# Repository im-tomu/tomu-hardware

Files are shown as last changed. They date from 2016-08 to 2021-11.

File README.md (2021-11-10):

# Tomu Hardware

[I'm Tomu](tomu.im) a tiny ARM microprocessor which fits in your USB port.
I have two buttons and two LEDs.

Tomu Front Render
Tomu Back Render

## Contact

We're available on mailing lists and IRC:

* [IRC Channel - irc://irc.freenode.net/#tomu](https://webchat.freenode.net/?channels=#tomu) - IRC channel for discussing anything related to the project.
* [Announcement mailing list](https://groups.google.com/forum/#!forum/tomu-announce/join) - Low traffic list for announcements.
* [Discussion mailing list](https://groups.google.com/forum/#!forum/tomu-discuss/join) - List for discussing development / new features / etc.

## About the PCB

Built out of a 3D printed part + 2 layer "thin" PCB.  LCA2018 and Crowd Supply
boards are 0.6mm.

Designs and documentation are available in:

* [`pcb/`](./pcb): [KiCad](http://kicad.org/) design files
* [`docs/`](./docs): PDF schematics, pin-out diagrams, and 3D renders

The board requirements are very lo-fi:

* 6mil traces
* 6mil clearance
* 0.3mm drill / 0.6mm vias

The primary MCU is a Silicon Labs EFM32HG309 ([datasheet](https://www.silabs.com/Support%20Documents/TechnicalDocs/EFM32HG309.pdf), [reference manual](https://www.silabs.com/Support%20Documents/TechnicalDocs/EFM32HG-RM.pdf)).

The important features are:

* [Available on Digikey](http://www.digikey.com/product-detail/en/silicon-labs/EFM32HG309F64G-A-QFN24/336-3207-ND/5142721)
* QFN24 - 5mm x 5mm package
* Inbuilt 5V to 3V3 regulator.
* Crystal-less USB

These make something which is almost hand solder-able fit into the tiny size.

## BOM

All parts are available from Digikey, and are readily available from other suppliers.

* [Kitspace Page](https://kitspace.org/boards/github.com/im-tomu/tomu-hardware/) has links to buy from multiple retailers and download the Gerbers
* [Digikey BOM in CSV format](bom-digikey.csv)
* [Digikey Shared Cart](http://www.digikey.com.au/short/39z1zv)

### Individual Parts

* Resistors
  * 2 x 0402 - 15 Ohm - [Digikey](https://www.digikey.com.au/short/3m8rz5)
  * 2 x 0402 - ~50 Ohm (Depends on LED choice)
* Capacitors - [Digikey Capacitors 0402, >1uF](https://www.digikey.com.au/short/3m8r4z)
  * 2 x Capacitor 1uF 0402
  * 1 x Capacitor 4.7uF 0402
* 2 x LED 0402
  * You choice of two different colors (might require adjustment of R1/R2).
  * 5mA LEDs are better choice.
  * Get highest millicandela rating you can.
  * [Digikey Search of LEDs in 0402 package](https://www.digikey.com.au/short/3m8rz0)
* 1 x EFM32HG309 or EMF32HG308

## Case

The PCB is thinner than a USB socket, and has exposed contacts on the reverse side, so it _needs a case_ in order to make proper contact with the USB pins, and to not short on the shield of the USB port.

Early prototypes used a business card that had been folded over, however the crowd funding campaign made enough to cut steel and make a case.

Designs are available in the [`case/`](./case) directory.  Cases for earlier board versions tend to require higher tolerance on 3D printers.

## FAQ

### Why did you create this?

The aim was to prove that a device which fits in your USB port could be created
**by hobbyists in small quantities** extremely cheaply.

### Where does the name Tomu come from?

TOMU comes from the abbreviation "Tim's Open Micro USB".

### What can I use this for?

What ever you want! If you do create something, please send me the info!

## License

The contents of this repository excluding [`third_party`
directory](./third_party) is released under your choice of the following two
licences:

* the "Creative Commons Attribution-ShareAlike 4.0 International License"
  (CC BY-SA 4.0) full text of this license is included in the
  [LICENSE.CC-BY-SA-4.0](LICENSE.CC-BY-SA-4.0) file and a copy can also be
  found at http://creativecommons.org/licenses/by-sa/4.0/
* the "TAPR Open Hardware License" full text of this license is included
  in the [LICENSE.TAPR](LICENSE.TAPR) file and a copy can also be found at
  http://www.tapr.org/OHL

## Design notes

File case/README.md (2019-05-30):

Tomu Cases
==========

The Tomu PCB has USB contacts on one side, but the other side contains components.  The combined height may not be enough to keep the Tomu PCB inside the USB port.

Early revisions of Tomu used a piece of folded paper to keep the PCB secure.  These cases were designed to alleviate this need.

The cases are designed in FreeCAD, and are distributed both in their source form and their production form.

[tomu\_0.2\_case](tomu_0.2_case.stl)
-------------------------------------

This is the original case.  It is a rectangle, and should work well.

[tomu\_0.2\_case\_fancy](tomu_0.2_case_fancy.stl)
----------------------

This is a fancier case.  It is designed to work with 0.8mm boards, and has a space cut out for the MCU.  It has a lip on the end.

[tomu\_0.3\_case](tomu_0.3_case.stl)
---------------

The Tomu 0.3 revision includes notches on the side for alignment with the PCB.  This case is the same as tomu\_0.2\_case\_fancy, but includes nubs to mate with the notches.

[tomu\_0.4\_case](tomu_0.4_case.stl)
---------------

The Tomu 0.4 revision is 10mm wide, enabling more material on the side for stronger rigidity.  Additionally, an alignment hole was added to the PCB, and this case has a corresponding peg.  Guide rails were added to the sides to make it easier to fit into a USB slot.

[tomu\_0.4\_case\_manufactured](tomu_0.4_case_manufactured.step)
---------------

A .STEP version of the Tomu case that was actually manufactured.  This includes plastic snap tabs to hold the PCB in place, and makes it easier to remove from the slot.

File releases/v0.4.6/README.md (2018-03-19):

# v0.4.6: Crowd Supply Release

This directory contains files for the v0.4.6 production run.

These boards were released as part of the Crowd Supply campaign.

# Files

* [`gerber/`](./gerber): Files output by KiCad
* [`pannelized/`](./pannelized): Pannelization as done by the factory

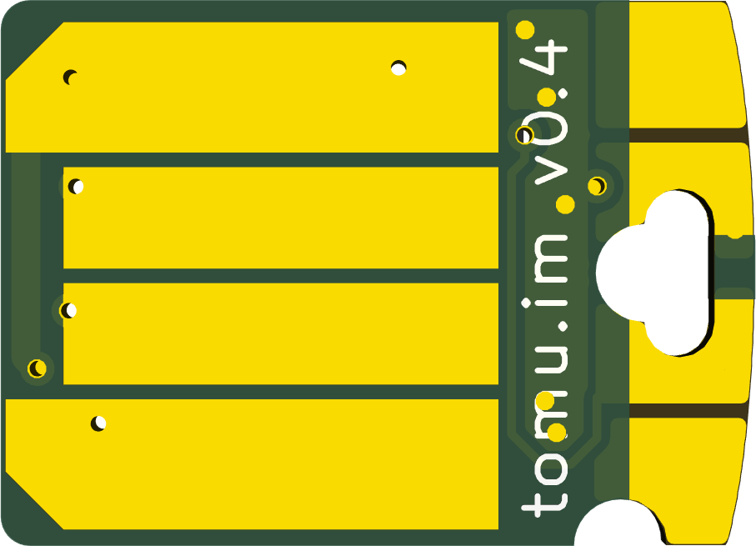
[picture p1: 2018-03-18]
docs/tomu-top-3d.png

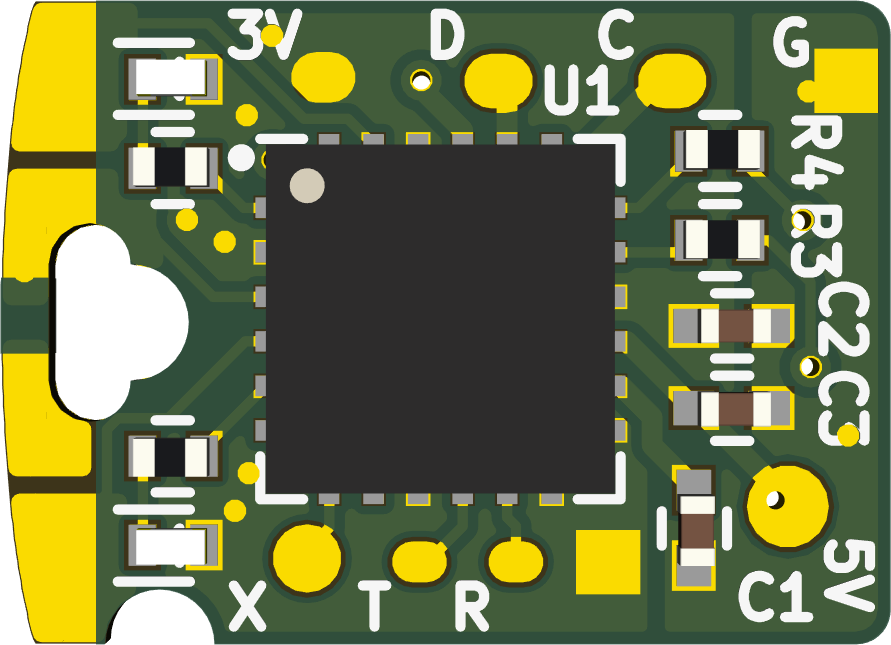
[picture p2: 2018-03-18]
docs/tomu-bottom-3d.png

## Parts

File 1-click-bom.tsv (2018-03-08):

References | Qty | Description | Manufacturer | MPN | Manufacturer | MPN | Manufacturer | MPN | Digikey | Mouser | RS | Newark | Farnell
R3 R4 | 2 | RES SMD 15 OHM 1% 1/16W 0402 | YAGEO (VA) | RC0402FR-0715RL |  |  |  |  | 311-15LRCT-ND | 603RC0402FR0715RL | 6788800 | 26M6782 | 9239014
U1 | 1 | IC MCU 32BIT 64KB FLASH 24QFN | SILICON LABORATORIES INC | EFM32HG309F64G-B-QFN24 | SILICON LABORATORIES INC | EFM32HG309F64G-A-QFN24 |  |  | 336-3896-ND | 634HG309F64GBQFN24 | 8727104 | 47Y0779 | 2475985
C1 C2 | 2 | CAP CER 1uF 10V X5R 0402 | AVX CORPORATION (VA) | 0402ZD105KAT2A | Taiyo Yuden | TMK105BJ105MV-F | Murata | GRM155R61A105ME15D | 587-3245-1-ND | 963TMK105BJ105MVF | 8145237 | 06M4041 | 1740588
C3 | 1 | CAP CER 4.7uF 6.3V X5R 0402 | MURATA ELECTRONICS (VA) | GRM155R60J475ME47D | Taiyo Yuden | JMK105BBJ475MV-F |  |  | 587-2787-6-ND | 963JMK105BBJ475MVF | 8145230 | 68X2780 | 2426952
D1 | 1 | LED GREEN CLEAR 0402 SMD | KINGBRIGHT COMPANY LLC (VA) | APG1005VGC-T-5MAV |  |  |  |  | 754-1815-1-ND | 604APG1005VGCT5MAV | 1246874 | 23X4794 | 2062324
R1 R2 | 2 | RES SMD 52.3 OHM 1% 1/16W 0402 | YAGEO (VA) | RC0402FR-0752R3L |  |  |  |  | YAG3180CT-ND | 603RC0402FR0752R3L | 7014444 | 90W3929 | 2140645
D2 | 1 | LED RED 0402 SMD | PANASONIC ELECTRONIC COMPONENTS (VA) | LNJ247W82RA |  |  |  |  | LNJ247W82RACT-ND | 667LNJ247W82RA | 7870207 | 66W2425 | 2112119

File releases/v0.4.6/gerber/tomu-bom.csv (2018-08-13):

Reference | Value | Footprint | Count | Datasheet | FootprintLib | MPN | Manufacturer | Description | Notes
C2 | 1uF, 10V, X5R, 0402 | C_0402 | 1 |  | Capacitors_SMD | ANY | ANY
C3 | 4.7uF, 6.3V, X5R, 0402 | C_0402 | 1 |  | Capacitors_SMD | ANY | ANY
C1 | 1uF, 10V, X5R, 0402 | C_0402 | 1 |  | Capacitors_SMD | ANY | ANY
P3 | USB-PCB | USB-PCB | 1 |  | usb-pcb |  |  | USB pads on bottom of PCB | DNP
R3 | 15 Ohm, 1%, 1/16W, 0402 | R_0402 | 1 |  | Resistors_SMD | ANY | ANY
R4 | 15 Ohm, 1%, 1/16W, 0402 | R_0402 | 1 |  | Resistors_SMD | ANY | ANY
D1 | LED Green 0402 | LED_0402 | 1 |  | LEDs | ANY | ANY
D2 | LED, Red, 0402 | LED_0402 | 1 |  | LEDs | ANY | ANY
R2 | 100 Ohm, 1%, 1/16W, 0402 | R_0402 | 1 |  | Resistors_SMD | ANY | ANY
R1 | 100 Ohm, 1%, 1/16W, 0402 | R_0402 | 1 |  | Resistors_SMD | ANY | ANY
W1 | CAP0 | Test_Point_2Pads | 1 |  | Measurement_Points |  |  | Capacitive touch pads | DNP
W2 | CAP1 | Test_Point_2Pads | 1 |  | Measurement_Points |  |  | Capacitive touch pads | DNP
U1 | EFM32HG309 | QFN-24-1EP_5x5mm_Pitch0.65mm | 1 | https://www.silabs.com/documents/public/data-sheets/EFM32HG309.pdf | Housings_DFN_QFN | EFM32HG309F64G-B-QFN24 | Silicon Laboratories Inc
P2 | DEBUG | pads-1x3 | 1 |  | usb-pcb |  |  | Test points for SWD | DNP
P4 | RESET_PAD | pads-1x1 | 1 |  | usb-pcb |  |  | Test point for RESET line | DNP
P5 | 5V_PAD | pads-1x1 | 1 |  | usb-pcb |  |  | Test point for supplying 5V power | DNP
XX1 | Button solder mask removal | soldermask-removal | 1 |  | usb-pcb |  |  | Internal component to expose captouch pads | DNP
XX3 | ESD Bag |  | 1 |  |  |  |  | Small bag to contain PCB and plastic case. Approx. 90mm x 90mm. | DNP
XX4 | Plastic Case |  | 1 |  |  |  |  | Case to be consigned from external plastics vendor | DNP
P1 | USART0 | pads-1x3-slim | 1 |  | usb-pcb |  |  | Test points for serial | DNP
P6 | 3V_PAD | pads-1x1 | 1 |  | usb-pcb |  |  | Test point for 3.3V power | DNP
XX2 | ESD Bag Sticker |  | 1 |  |  |  |  | Black-and-white sticker to affix to ESD bag. 30mm x 50mm | DNP

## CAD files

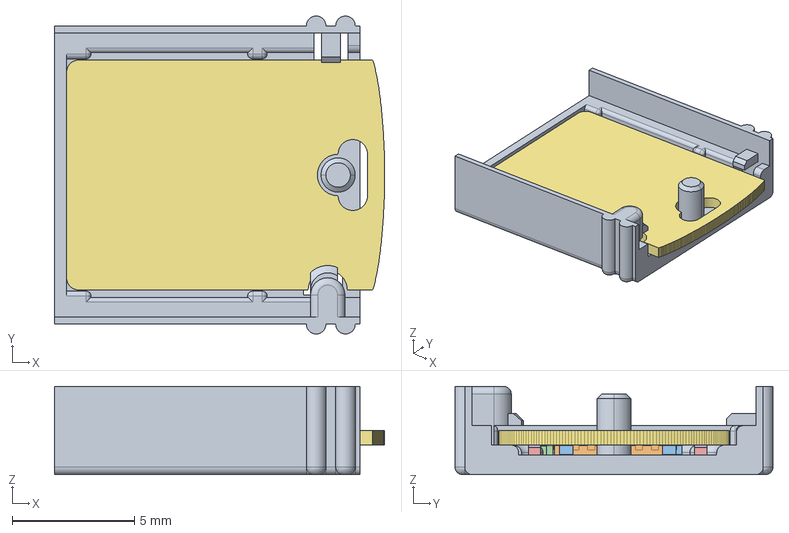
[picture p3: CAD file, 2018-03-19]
case/tomu_0.4_case_manufactured.step
13.5 x 13.0 x 3.60 mm
TOMU_0_4_CASE_SHORT-V01
QFN-24-1EP_5X5MM_PITCH0_65MM_
R_0402_002
R_0402_003
R_0402_001
R_0402_
C_0402_
MANIFOLD_SOLID_BREP_28906
MANIFOLD_SOLID_BREP_29236
C_0402_001
C_0402_002
MANIFOLD_SOLID_BREP_69845
MANIFOLD_SOLID_BREP_70175
PCB

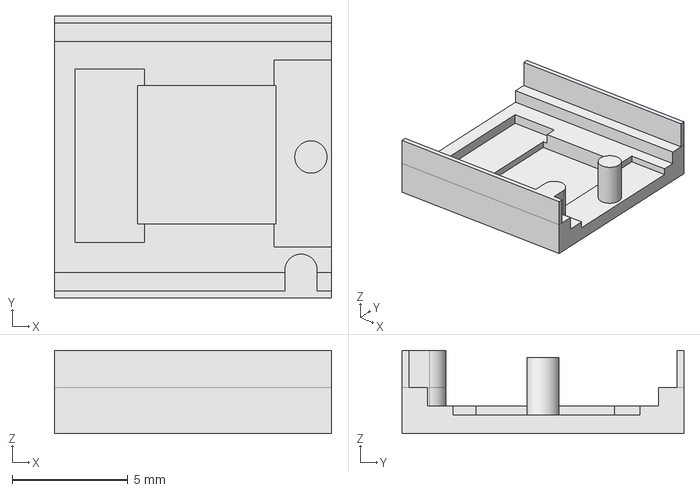
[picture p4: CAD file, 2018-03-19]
case/tomu_0.4_case.step
12.0 x 12.2 x 3.60 mm

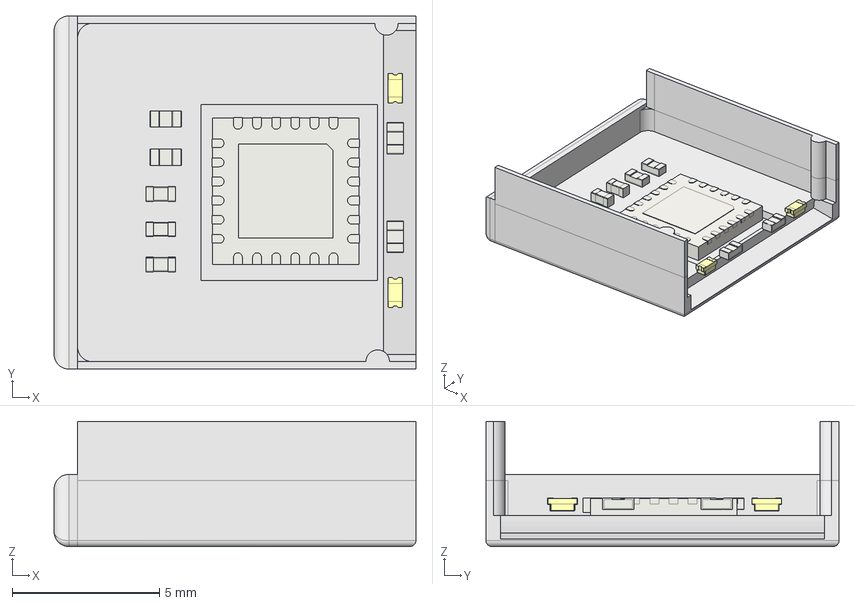
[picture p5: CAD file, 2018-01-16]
case/tomu_0.3_case.FCStd
12.3 x 12.0 x 4.25 mm
R_0402_
User Library-led_0402_
C_0402_
C_0402_001
C_0402_002
User Library-led_0402_001
R_0402_001
R_0402_002
R_0402_003
QFN-24-1EP_5x5mm_Pitch0.65mm_

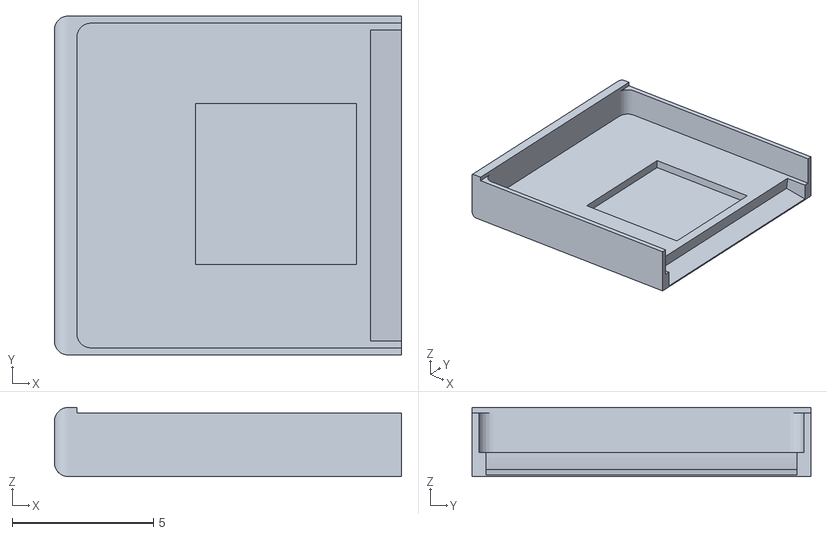
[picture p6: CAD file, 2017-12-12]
case/tomu_0.2_case_fancy.stl
12.3 x 12.0 x 2.45

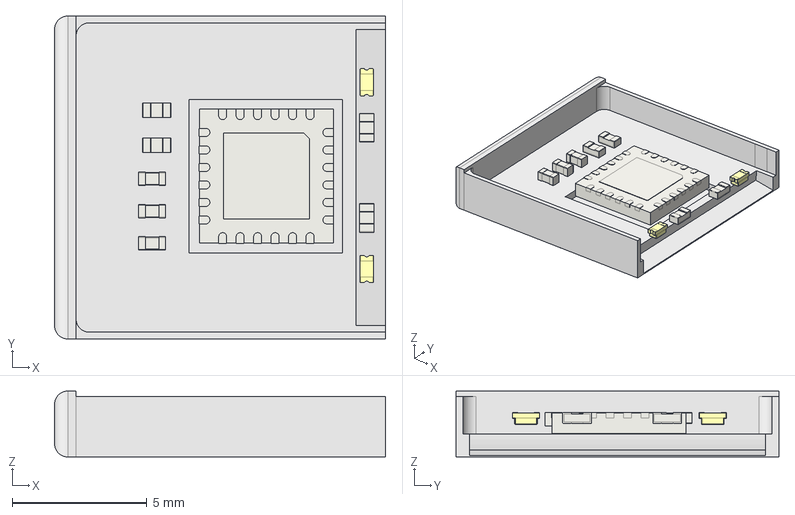
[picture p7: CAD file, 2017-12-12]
case/tomu_0.2_case.FCStd
12.3 x 12.0 x 2.45 mm
R_0402_
User Library-led_0402_
C_0402_
C_0402_001
C_0402_002
User Library-led_0402_001
R_0402_001
R_0402_002
R_0402_003
QFN-24-1EP_5x5mm_Pitch0.65mm_

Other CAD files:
case/tomu_0.4_case_short.step
case/tomu_0.2_case.stl
case/tomu_0.3_case.stl
case/tomu_0.4_case.FCStd
case/tomu_0.4_case.stl

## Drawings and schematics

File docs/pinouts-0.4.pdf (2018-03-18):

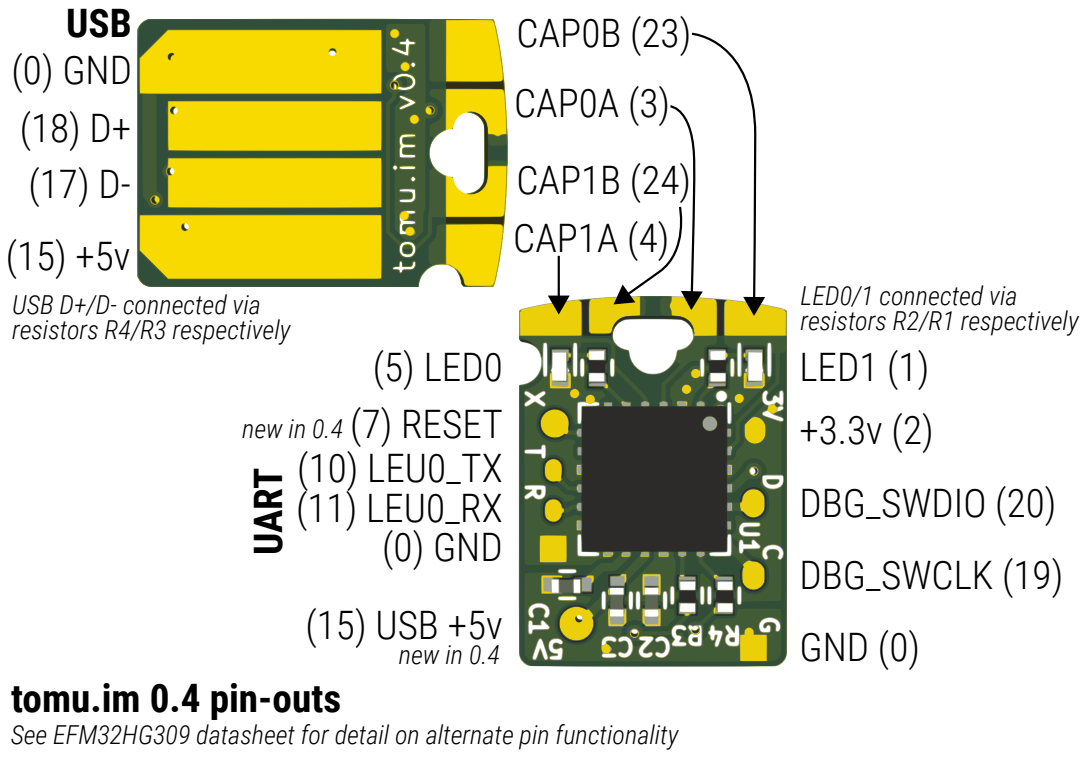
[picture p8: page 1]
DBG_SWDIO (20); DBG_SWCLK (19); GND (0); LED1 (1); CAP1A (4); CAP1B (24); CAP0A (3); CAP0B (23); (0) GND; USB; USB D+/D- connected via resistors R4/R3 respectively; (7) RESET; (5) LED0; (15) USB +5v new in 0.4; new in 0.4 (10) LEU0_TX (11) LEU0_RX; UART; LED0/1 connected via resistors R2/R1 respectively

tomu.im 0.4 pin-outs
See EFM32HG309 datasheet for detail on alternate pin functionality

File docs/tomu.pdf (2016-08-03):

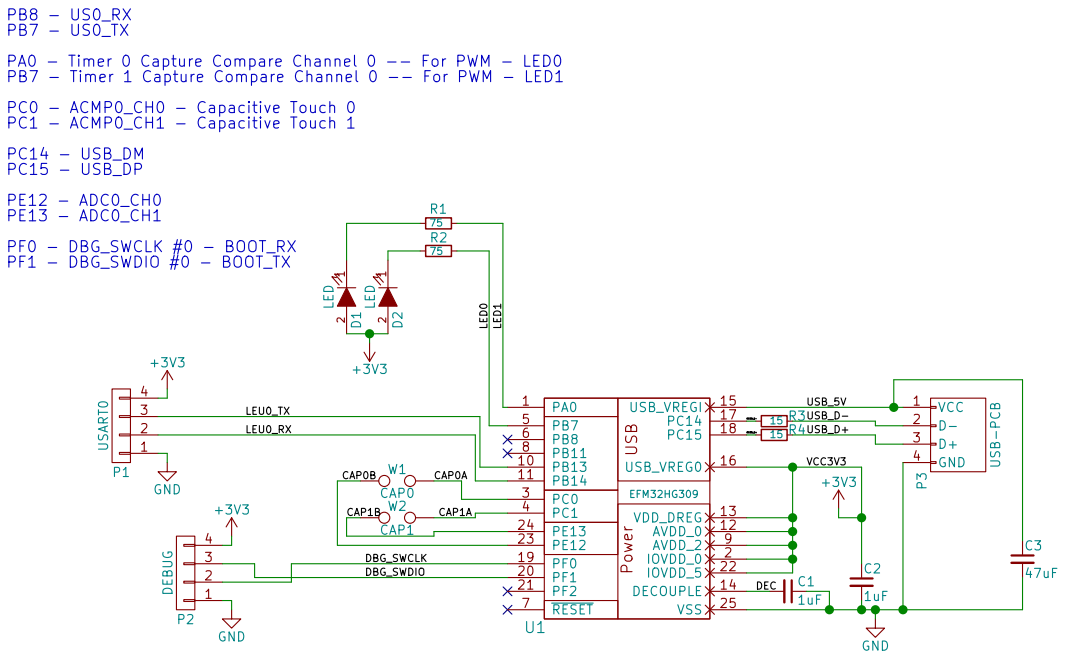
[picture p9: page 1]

https://github.com/mithro/tomu C2
1uF GND

http://tomu.im
License: CC-BY-SA 4.0 or TAPR
File: tomu.sch Sheet: / Tim 'mithro' Ansell <mithro@mithis.com>

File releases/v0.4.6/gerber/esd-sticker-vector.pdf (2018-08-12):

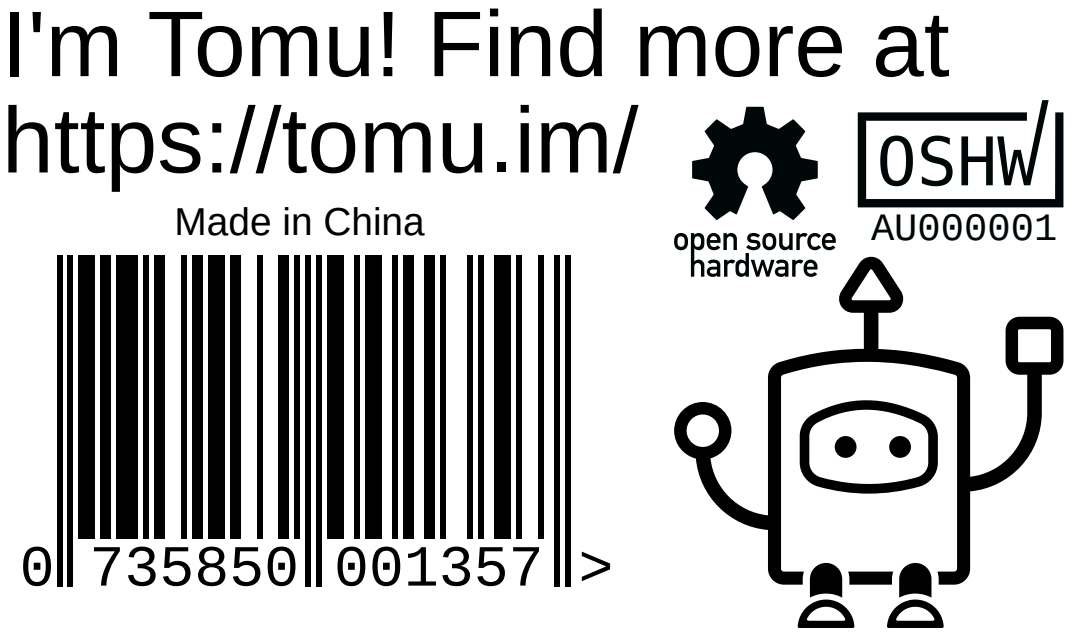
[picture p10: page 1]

I'm Tomu! Find more at
https://tomu.im/

Made in China

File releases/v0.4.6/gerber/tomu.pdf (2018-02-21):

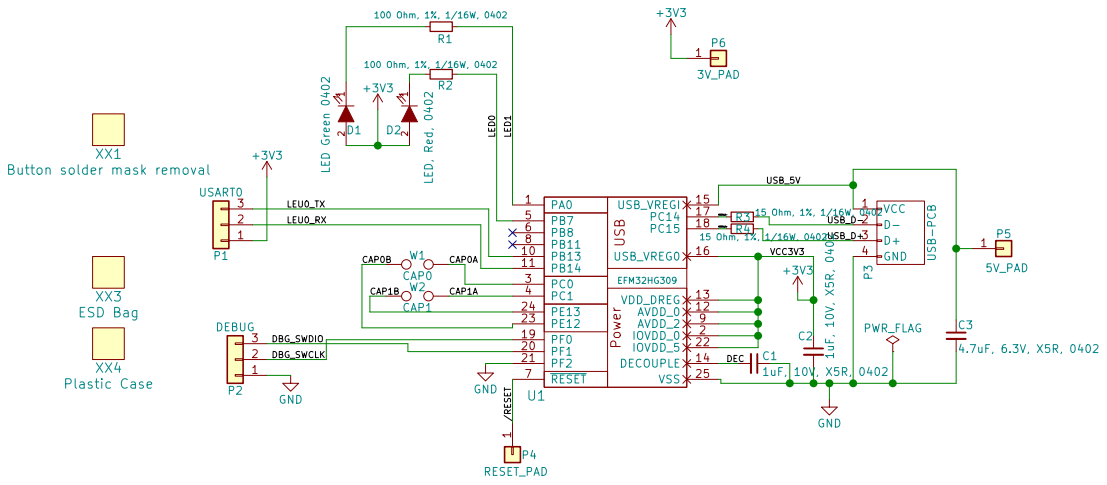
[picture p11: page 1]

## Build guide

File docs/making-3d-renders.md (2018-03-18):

# Making 3D renders

This walks through the steps involved in making a 3D render, and annotating it in an SVG file.

You'll need both KiCad and Inkscape installed. This document assumes some level of familiarity with Inkscape.

## Render the PCB

1. Load `./pcb/tomu.pro` in KiCad.

2. Open `tomu.sch` from within the project.

3. `View` > `3D Viewer`.

Viewport parameters used for export:

- `dx` = 0
- `dy` = 0
- `zoom` = 16.4
- `background colour`: white (#FFFFFF)

Use the fixed top view and bottom view.  Bottom view also requires rotation on the Y axis by 180 degrees.

Export as PNG.  Flatten the image and autocrop.

These should come out as:

- Top: 907x655 px
- Bottom: 891x645 px

Don't worry about resizing them or if they don't match exactly. You just need to get "enough" resolution that it looks nice in Inkscape.

## Import into Inkscape

Parameters used for Inkscape:

- Page size: A4 (landscape) / 297 x 210 mm
- Object size: 100mm wide (fixed aspect ratio)

Import the two images (the top and bottom) into Inkscape, into the same document.

For each image:

1. `Path` > `Trace Bitmap`

2. Select `Multiple Scans` > `Colors`, and tick `Remove background`.  Other options should be left as defaults.

3. Click `OK`.  This will take a couple of seconds to scan the image (the OK button will be disabled while processing), and then you can close the Trace window.

4. The Trace (group) will be placed on top of the Image.  Move them apart, and delete the Image, so you have only the trace.

5. Adjust the size of the trace to be 100mm width (fixed aspect ratio).

Save the document as SVG.  You will now have two vectors that you can use to annotate the PCB in Inkscape.

## Style

The main font used is `Roboto Condensed`.

* Headers: Bold font width
* Other text: Light font width

## PDF

Export as PDF using Inkscape. Include embedded fonts.

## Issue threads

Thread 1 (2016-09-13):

Commit design for 3d printable case

mithro, 2016-09-13:

mithro, 2016-09-13:
@phlipped can you send me a pull request with the design in it? Thanks!

mithro, 2017-01-06:
This was done in https://github.com/im-tomu/tomu-hardware/pull/11

Closed 2017-01-06.

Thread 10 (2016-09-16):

Create a QEMU emulation environment

mithro, 2016-09-16:
@shenki was doing something here....

shenki, 2016-09-16:
Follow along at https://github.com/shenki/qemu/tree/efm32hg

Current state builds but does not work. I've got local changes that implement the leuart, will push once they are working.

mithro, 2016-09-16:
How hard / possible is emulating the USB side of things?

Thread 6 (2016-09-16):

Test the LEUART

mithro, 2016-09-16:
Test that the LEUART can be used on the UART pins.

joshgoes, 2016-09-16:
The D and C pins are LEUART0 location 3, and T and R pins are LEUART0 location 1.

Because D and C are also used by ARM SWD (which is enabled by default), it's important to remember to configure the multiplexer to use location 1 when enabling the LEUART.

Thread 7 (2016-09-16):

Test the ARM SWD

mithro, 2016-09-16:
Test that the CPU can be debugged via the ARM SWD pins using OpenOCD and GDB.

maks, 2017-01-20:
@mithro which pads on the board are the SWD pins brought out to?
I want to have a go at using SWD with a buspirate and openocd to do the initial flashing [per this guide](https://www.earth.li/~noodles/blog/2015/08/program-fst01-with-buspirate.html).

sa-wilson, 2017-01-27:
@maks C and D are the SWD pins. CLK and DIO respectively.

I screwed up the UART bootloader upgrade and then had to use OpenOCD and an STLink-v2-1 to flash the bootloader back, so I know that particular combination works. Only OpenOCD 0.10 has Happy Gecko support though. I didn't try any debugging.

mithro, 2017-02-03:
Instructions on using ARM 2-wire with OpenOCD on a RPi are now at
https://github.com/im-tomu/tomu-bootloader/tree/master/openocd

It's definitely working, so closing this issue.

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

Closed 2017-02-03.

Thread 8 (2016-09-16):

Create a easy programmer rig

mithro, 2016-09-16:
Something with spring-loaded contacts / pogo pins....

mithro, 2016-09-16:
Needs a USB->Serial interface to enable loading of the initial firmware.

maks, 2017-01-20:
Only just started reading the [mcu's documentation](https://www.silabs.com/Support%20Documents/TechnicalDocs/EFM32HG309.pdf) and initially spotted:

> 2.1.13 Pre-Programmed USB/UART Bootloader

Is there a reason why this can not be used for easy firmware flashing?

maks, 2017-01-20:
Reading the [app note](https://www.silabs.com/Support%20Documents/TechnicalDocs/AN0042.pdf) you can use either USB or UART, so I guess next question is are the T/R pins USART0 ?

joshgoes, 2017-01-20:
> Is there a reason why this can not be used for easy firmware flashing?

Yes - the pre-programmed USB/UART Bootloader depends on an external high-frequency XTAL for USB functionality, despite there being a perfectly good internal high-frequency XTAL for USB. This is an oversight on Silicon Labs' part. As the Tomu has no external XTAL, the USB functionality is nonexistent. This is why we have to use the (Silicon Labs provided) AN0042 bootloader. It is more-or-less identical to the factory-programmed bootloader but with the XTAL stuff fixed up, and the version string changed slightly.

> Reading the app note you can use either USB or UART, so I guess next question is are the T/R pins USART0 ?

The UART mentioned in the bootloader docs is actually an LEUART, which is wired to the D/C pins. This means that the D/C pins are used by both SWD as well as a low-energy UART.  The T/R pins are wired to a different UART to the D/C pins. This allows people to have SWD and UART (or two UARTs) going at the same time.
I can't remember in which doc (or where in the doc), but there's a table of all the peripherals plus their "locations" -- with pins. Check out the Tomu schematic to find which pins T/R are wired to, and then check the table to see which UART+Location combos are available at those pins.

maks, 2017-01-20:
Now that @mithro emailed out about the project discuss google group, I see the post there from @joshgoes already covers how to use the builtin bootloader to flash via uart.

kevinb456, 2018-11-14:
I've just noticed this on a browse of interesting kitspace.org projects - I have had success in my work capacity in designing simple programming sprung-probe rigs so could share some ideas for this.

I've found that a mechanical base designed in Freecad, and printed on a 3D printer can be quite effective. Probes/sleeves such as Harwin P19-4021 and S19-501 can contact to the SWD pins, and can be inserted straight into the 3D printed base if designed with a tight fit. Also attach a clamp such as Brauer H100/2 to the base which brings a second 3D printed 'press' part down on top of the PCBA. Then combining with a programmer such as an LPC-Link2, and the whole thing bundled up inside a plastic enclosure works well - insert PCBA, close press with handle, program PCBA, open press & remove... rinse&repeat! Depending on volume this could be expanded to do a panel at once with multiple programmers.

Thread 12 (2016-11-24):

Make the tomu PCB work with OSH park

mithro, 2016-11-24:
See http://docs.oshpark.com/submitting-orders/cutouts-and-slots/

Currently the slot doesn't work;

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

flummer, 2016-12-30:
I'll be happy to look into this... Since this slot isn't plated (that would short two of the pads), this can be milled along with the outline, so if the hole is replaced with an additional outline (inside cut-out), the same file should work with OSH park and the other fab houses.

I'll be happy to do that and send a pull request, just need to separate some of the stuff in the current design first.

pdp7, 2017-02-14:
Hi @flummer, thanks for making this change.  I work for OSH Park and have just ordered your modified version: https://oshpark.com/projects/4tCH773A

I used our 0.8mm thickness service.  Our normal 1.6mm thick 2 layer panels go out daily, but this one is less frequent.  The current 0.8mm panel is already at 50%, so it should be going to fab on Friday.  I should have it be the end of February.

I'll order an OSH Stencil and the parts and attempt to assemble.  I've used paste before with SOIC but not a QFN, so it will be an interesting experience.

bokowski, 2018-02-26:
One year later... I thought I'd update this issue saying that the board (OSH Park link above) works.

vincenttl, 2018-03-27:
Hi, I build a Tomu from oshpark: https://oshpark.com/shared_projects/ZAMlmpMB
It seems to be working.
Got the bootloader running and this too https://github.com/im-tomu/chopstx/tree/efm32/example-tomu

The touch seems to work fine. Anything else I should try?

mithro, 2018-04-02:
Got some pictures? Did the hole/slot work?

vincenttl, 2018-04-02:
Here is one of the 3. It would need to be cleaned up a little bit.
I also left it a bit too long on the hot plate for soldering.

I continued playing with it and there might be an issue.
I flashed the dfu bootloader without issue but it comes back to the
bootloader every power cycle even if I used dfu-utils to program the u2f
firmware. I checked for a short between the outer pads and they are not
shorted.

I'll investigate soon.

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

todbot, 2018-04-02:
The bootloader always running is not a short in your circuit.  It's apparently by design: https://github.com/im-tomu/tomu-bootloader/issues/31

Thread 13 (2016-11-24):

Order and test tomu boards from Dirty PCBs

mithro, 2016-11-24:
http://dirtypcbs.com/

mithro, 2016-11-24:
Your order number:2027981
```
PCBs	File	Layers	Size (actual)		Color	Thickness	Coating	Stencil	Processing	Quantity	Charge	Status
28514	xx	2	5x5cm(1.1x1.3cm)	Yellow	1.0mm		HASL	None	Normal		Protopack ±10	$14	Order received

Shipping	Hongkong Airmail (1-8+ weeks)	$0	0.1kg
Total	 	$14
xxx - tomu-v0.2-11-g07748ae.zip
```

mithro, 2016-11-24:
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

luftek, 2017-01-28:
DirtyPCB do panelized 2 layer boards. Like:
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

I use https://github.com/ThisIsNotRocketScience/GerberTools , works great. Their tools are also used for rendering the DirtyPCBs

A append an example of your v0.2 board but multiplied on a 10x10cm prototype panel. Roughly 36 times 10-12 panels which is around **400pcs for 25$ (panel + shipping)**
Your panelized board would look like that:
- choose red color :)
- breaktabs can be made smaller, for easier depanelization
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

I make a pull request?

mithro, 2017-01-30:
Make sure you order the thinner PCB - please do send a pull request.

luftek, 2017-01-30:
I don't have a use for im-tomu right now -> won't order samples.
Just wanted to let you know. Tell which size you choose for panelizing (5x5 OR 10x10 cm) and I will do it (pull request).

mithro, 2017-01-30:
Lets do both?

luftek, 2017-01-30:
Sure

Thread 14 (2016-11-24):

Order and test tomu boards from Seeed Studio

mithro, 2016-11-24:
https://www.seeedstudio.com/fusion.html

mithro, 2016-11-24:
```
Fusion PCB
SKU: 501010001
$9.90 × 1
PCB Dimension - 11mm*13mm
Impedance Control - No
Surface Finish - Hasl
Copper Weight - 1oz.
Half-cut / Castellated Holes - No
Min Hole Size - 0.3mm
PCB Color - Blue
Material - FR4
Layer - 2
PCB Qty. - 10
Blind Vias - No
PCB Thickness - 1.0mm
Min Tracking / Spacing - 6/6mil
Panelized PCBs - 1
File - D_358425_tomu_v0_2_11_g07748ae.zip
```

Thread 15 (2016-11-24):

Panelize the tomu board -- for cheaper production

mithro, 2016-11-24:

luftek, 2017-01-28:
Check #13

xobs, 2018-09-11:
There are pannelized gerbers in https://github.com/im-tomu/tomu-hardware/tree/master/releases/v0.4.6/pannelized, which are the actual files used during production.

Closed 2018-09-11.

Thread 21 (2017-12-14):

U1 pin 1 marker is confusing

xobs, 2017-12-14:
The "pin 1" marker for U1 is very subtle, and multiple assembly shops have had trouble identifying it.

"pin 1" should be changed to use the more traditional "pin 1 dot", rather than the current arrangement of a broken box.

xobs, 2018-03-09:
This was fixed in v0.4

Closed 2018-03-09.

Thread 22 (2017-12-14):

Reset pin not connected

xobs, 2017-12-14:
The /RESET pin (pin 7 of the MCU) is not made available. This is an issue when working on the bootloader.

Ordinarily, the system relies on being able to send a JTAG reset. This is fine if the MCU isn't locked up. However, if the MCU crashes then it is impossible to reattach gdb without a reset.

In order to develop on the bootloader itself, /RESET should be brought out to a pad.

xobs, 2018-03-09:
This pin is brought out in v0.4

Closed 2018-03-09.

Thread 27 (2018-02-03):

Flashprint complains the 0.4 short case has errors

deece, 2018-02-03:
No details provided, my guess is the STL fails the manifold check.

xobs, 2018-02-03:
I don't have Flashprint, so I can't reproduce.  However, I've run that STL file through MeshFix.  Does 39df12e0c3616080f021085e6e30da3359f7ce82 solve the issue?

deece, 2018-02-08:
Yup, that fixed it, thanks

Closed 2018-02-08.

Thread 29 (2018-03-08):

Schematics image, but with a photo/diagram of the physical layout

micolous, 2018-03-08:
I was having a look to see what is brought out from the EFM32HG309 on the back of the board, and so my first port of call was `/docs/tomu.pdf`.  But this shows the logical layout.  There's also no indication about which version of the board it applies to.

What would help is if there were pictures/diagrams of the actual, physical layout of the board, pointing to what each pad corresponds to on the EFM32HG309.

This would help people who are less skilled with electronics to know what they're wiring on to.

I _think_ what it is:

- The 4 pads on the top labelled with "D" and "C" are the debug interface, and, from left to right:
  1. 3.3v
  2. SWDIO
  3. SWDCLK
  4. Ground (square)
- The 4 pads on the bottom, labelled with "T" and "R" are the (Low Energy) UART interface, and, from left to right:
  1. 3.3v
  2. PB13 / LEU0_TX
  3. PB14 / LEU0_RX
  4. Ground (square)
- The four contacts on the left edge are the touch-sensitive pins, not sure what is connected to what there, but could also be repurposed for analogue or digital I/O.

mithro, 2018-03-08:
There is some info here -> https://github.com/im-tomu/tomu-bootloader/tree/master/openocd#wiring

mithro, 2018-03-08:
We would love for someone to create pin diagrams like those found on http://fritzing.org/parts/ or http://diwo.bq.com/pinout-uno/

Closed 2018-03-18.

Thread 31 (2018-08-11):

ROHS compliance

InnovativeInventor, 2018-08-11:
I see that all of the components listed [here](https://github.com/im-tomu/tomu-hardware/blob/master/bom-digikey.csv) are ROHS compliant (awesome!), but is the solder you use ROHS compliant as well? Also, are there plans to get tomu ROHS-certified? Keep up the good work!

InnovativeInventor, 2020-07-31:
Update: https://groups.google.com/forum/#!topic/tomu-discuss/4NW_Z1UTspo

Closing the issue for now.

Closed 2020-07-31.

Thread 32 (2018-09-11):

Minor inconsistency in BOM documentation.

hackup, 2018-09-11:
The README lists "1 x Capacitor >10uF 0402" under "individual parts". In the other BOM documents and links presumably the same part is listed as 4.7uF.

xobs, 2018-09-11:
Thanks, fixed!

hackup, 2018-09-11:
I think this is still not quite right. According to the schematics, both C1 and C2 are 1uF and C3 is 4.7uF. There doesn't seem to be a cap >10uF.

hackup, 2018-09-11:
Glad to hear that because those are the components I ordered. :-) Thanks!

Closed 2018-09-11.

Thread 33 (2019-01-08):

Store data inside flash

dzonerzy, 2019-01-08:
As it states there's a way to store data inside tomu?

xobs, 2019-01-09:
To the best of my knowledge, there aren't any examples of this yet.  You need to be very, very careful, because you can very easily erase Toboot, meaning your board won't boot anymore.

An example of something that stores data on the flash is Booster (https://github.com/im-tomu/tomu-bootloader/blob/master/booster/main.c#L127), which is used to update Toboot.

Tomu has 1024-byte pages.  Since there are 64 kB on the device, that means there are 64 pages in total.  Toboot takes up the first 8 pages.

To program data, you must:

1. Erase a 1024-byte block
2. Program your data in 4-byte words.

That's what that loop does: It erases an 1024-byte block, then loops through the data to write and programs it 4-bytes at a time.

You _must_ erase a block before programming data, otherwise you can damage the flash.

As long as you make sure to never pass a `target_addr` that's <= 8192, the `ftfl_begin_erase_sector()` and `ftfl_begin_program_word()` functions can be used in your program.  To make life easier, you could make sure `target_addr` is always something towards the end of flash, like address 61440 (= 60*1024).

Closed 2019-01-09.

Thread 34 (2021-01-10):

simple small device

ojej, 2021-01-10:
Is possible create a small enclosure for tomu, qomu etc. for runing ruby, python or one program?
similar https://hackaday.com/2021/01/07/building-a-pocket-sized-python-playground/ or https://hackaday.io/project/169103-low-power-esp32-handheld

Simple: power (meybe solar too, AA), screen, some buttons, removable tomu.
I can writing a program but im not electronic ;-(
Simple, fast run device for mass

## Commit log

2016-07-26 Start of doing a "flex PCB" for USB key device.
    [usbkey.kicad_pcb, usbkey.sch]
2016-07-27 Actually have a design.
    [usbkey.kicad_pcb, usbkey.sch]
2016-07-27 Cleaning up some parts.
    [usbkey.kicad_pcb]
2016-07-28 Missing bracket.
2016-07-28 Give all the nets names.
    [usbkey.kicad_pcb, usbkey.sch]
2016-07-29 Playing with things.
    ADC on one side, capacitive on the other.
    Starting on USB PCB component.
    [usbkey.kicad_pcb, usbkey.sch]
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2016-07-29 Lots of modifications.
    Trying to make 5mil/5mil pass.
    [usbkey.kicad_pcb, usbkey.sch]
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2016-07-31 Fixing the D+/D- direction.
    * Still need to fix the board routing...
    [usbkey.kicad_pcb]
2016-07-31 Lots of small fixes.
    [usbkey.kicad_pcb]
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2016-08-01 Adding script from https://github.com/KiCad/kicad-source-mirror/tree/master/demos/python_scripts_examples
    Last modification was;
    274e88d on Dec 9, 2015
    hzeller Fix Python demo script gen_gerber_and_drill_files_board.py to choose
    one or 2 drill files when calling SetOptions() if NPTH pads are used.
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2016-08-01 Add two missing NC markers.
    [tomu.kicad_pcb, tomu.sch]
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2016-10-03 Update the BOM so Digikey doesn't charge $9 USD for a single LED.
    [bom-digikey.csv]
2016-12-07 Fixing 47uF with 4.7uF
    [tomu.kicad_pcb]
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2016-12-29 Closed small gap in Edge.Cuts layer
    Small gap prevented 3D viewer from properly rendering outline
    [tomu.kicad_pcb]
2016-12-30 Changed oblong NTPH hole to Edge.Cuts
    For the board to be manufactured with OSH park, that does not accept oblong NPTH holes, the cutout for the strap has been changed to an inside cutout, which should work with all the common manufactur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
    [tomu.kicad_pcb]
2017-10-30 pcb: add features for orienting a case
    Add some round features on the sides to allow for lining up the PCB with
    an external case.
    [tomu.kicad_pcb]
2017-11-04 pcb: fix up mounting holes
    [tomu.kicad_pcb]
2017-11-08 case: add case file for tomu 0.3
    This version has intendations for case alignment.
    This case assumes a PCB height of 0.6mm.
    [tomu_0.2_case.stl, tomu_0.3_case.FCStd, tomu_0.3_case.stl]
2017-11-14 case: fix up case dimensions for v0.3
    This corrects a problem with the edge dimension that was too short.
    [tomu_0.3_case.FCStd, tomu_0.3_case.stl]
2017-11-14 case: add fancy case for tomu-0.2
    This case is more form-fitting, and goes around the MCU.
    [tomu_0.2_case_fancy.stl]
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2017-12-10 pcb: fix missing U1 pad
    The U1 GND pad got removed somehow. Add it back in.
    [tomu.kicad_pcb]
2017-12-10 releases: v0.3: add generated files
    Add generated gerber files for v0.3.
    [tomu-B.Cu.gbl, tomu-B.Mask.gbs, tomu-B.Paste.gbp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]
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2018-01-09 case: add guiderails to v0.3 case
    These rails help to keep the PCB in place, and guide the assembly as it
    is inserted into the USB port.
    [tomu_0.3_case.FCStd, tomu_0.3_case.stl]
2018-01-10 usb-pcb: shrink PCB to 10mm wide
    This is the first step towards DFM for plastic.
    [tomu.kicad_pcb]
2018-01-10 v0.4: make board slimmer, increase tab size
    Make the board slimmer, which will make plastics easier to fabricate.
    Also make the tab size bigger, because that should be useful for
    something.
    [tomu.kicad_pcb, tomu.sch]
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2018-01-13 v0.4: rework board to be 1.0mm slimmer
    Rework the main PCB to be slightly slimmer, a total of 10mm wide. This
    allows us to have 1mm of space on each side, which is enough for an
    injection-molded case to be made.
    [tomu.kicad_pcb, tomu.sch]
2018-01-13 hardware: fix outline, replace phantom pad with real one
    There was a phantom pad that was created with an external graphic. It's
    unselectable in Kicad, and is weird. This pad exposes the soldermask on
    the captouch buttons.
    Recreate it as a real item.
    Additionally, fix the graphic outline.
    Additionally, move everything up to the corner, to fix drill files later
    on.
    [tomu.kicad_pcb, tomu.sch]
2018-01-13 case: pcb: add v0.4
    Add a PCB outline for Tomu 0.4.
    [tomu_0.4_pcb.FCStd]
2018-01-14 pcb: rotate LEDs by 90 degrees to free up the center
    Rotate the LEDs by 90 degrees. This frees up the center to allow for
    unrestricted area for plastics mating.
    [tomu.kicad_pcb]
2018-01-14 pcb: make slightly skinnier, route 3V better
    This makes the PCB a bit skinnier, to add margin for plastics. It also
    routes the 3.3V net better, for stability.
    [tomu.kicad_pcb, tomu_0.4_pcb.FCStd]
2018-01-14 case: add v0.4 case
    This is an RC, and must be verified.
    [tomu_0.4_case.FCStd, tomu_0.4_pcb.FCStd]
2018-01-16 pcb: position text properly on backside
    Move the text on the backside of the PCB so that it is positioned above
    the correct spot.
    [tomu.kicad_pcb]
2018-01-16 case: make v0.4 case fit in a USB port
    The previous design of the case didn't actually fit.
    This new design has 0.4mm slides that should be printable by most 3D
    printers, and should fit nicely into a USB slot.
    [tomu_0.4_case.FCStd]
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2018-01-16 case: muck around with v0.4 case
    Modify the size of the case so that it actually fits.
    [tomu_0.4_case.FCStd]
2018-01-28 case: add shortened version of the case
    This version is less tall, which should make production easier.
    [tomu_0.4_case_short.FCStd, tomu_0.4_case_short.step, tomu_0.4_case_short.stl]
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2018-02-03 case: run short case through MeshFix
    It has been reported that some programs don't accept the STL file
    produced by FreeCAD. Run the file through MeshFix to see if that solves
    the problem.
    [tomu_0.4_case_short.stl]
2018-02-03 Add missing kicad_pcb files to releases.
    [tomu.kicad_pcb]
2018-02-03 Add missing release (v0.0) to releases folder.
    [tomu-CuBottom.gbl, tomu-CuTop.gtl, tomu-EdgeCuts.gm1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]
2018-02-05 schematic: line up to 50 mil spacing
    Some components weren't on 50 mil spacing, making it hard to work
    with. Line everything (but the MCU) up to large spacing.
    [tomu.sch]
2018-02-05 pcb: expose 3.3V pad
    Expose the 3.3V pad on the back, to prevent the user from having to
    provide 5V power.
    [tomu.kicad_pcb]
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2018-02-05 pcb: use usb footprint with smaller mask
    Use the updated usb-pcb footprint with the soldermask pulled back.
    [tomu.kicad_pcb]
2018-02-05 pcb: move user drawings around a bit
    Move the user drawings for some of the new pads to places where they
    make more sense.
    [tomu.kicad_pcb]
2018-02-05 pcb: alter cutout, move edge vias
    Make the cutout sligntly smaller, and add extra vias to the edge. This
    makes drill selection easier for the PCB house, and increases the
    chances of getting captouch working well.
    [tomu.kicad_pcb]
2018-02-05 pcb: change user drawings to be more descriptive
    Update the user drawing values to make them more descriptive, e.g. going
    from "P1" to "Serial headers". This is because, while we can't delete
    this layer, it still shows up by default in the 3D viewer.
    [tomu.kicad_pcb]
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2018-02-14 pcb: add v0.4.4 with improved 5V rail
    The 5V trace is now bigger.
    [tomu.kicad_pcb]
2018-02-14 case: increase pocket size to 0.8mm
    This seems required.
    [tomu_0.4_case_short_v0.4.4.FCStd, tomu_0.4_case_short_v0.4.4.step, tomu_0.4_case_short_v0.4.4.stl]
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2018-02-21 pcb: add fill for GND for decoupling cap
    Add a ground pour for the decoupling cap in the corner.
    [tomu.kicad_pcb]
2018-02-21 pcb: increase copper going to 3.3V pad
    Reroute one captouch trace and use two vias to tap into the 3.3V rail on
    the backside. This gives us more reliable 3.3V on pin 2. Additionally,
    we now have two vias going to the backside 3.3V rail, which should
    improve the power flow to the other half of the board.
    [tomu.kicad_pcb]
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2018-03-18 Documentation improvements (fixes issue #29):
    - Adds 3D renders of the board, and instructions on how to make new ones.
    - Adds a pinout diagram (SVG and PDF versions included), and instructions on how to make new ones.
    The pinout diagram includes notes on what's changed since v0.3 (LCA 2018 build).
    - Normalises some Markdown formatting.
    - Moves all PCB design files to `./pcb`.
    - Updates `release.sh` to point at new paths, and points it at kitspace.yaml (from commit 33289ad)
    - Adds .DS_Store to .gitignore.
    [tomu.kicad_pcb, tomu.sch]
2018-03-19 release: add v0.4.6 pannelization
    This pannelization is what is used by the factory for production.
    [a.gbl, a.gbo, a.gbs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]
2018-03-19 case: add manufactured case, and clean up naming
    Remove "_short" from v0.4 case filenames, and add the manufactured file.
    Update the README file to reflect this change.
    [tomu_0.4_case.FCStd, tomu_0.4_case.step, tomu_0.4_case.stl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]
2018-08-11 0.4.6: add pick-and-place file
    This file is converted from the KiCad .pos file to a standard .csv file.
    [tomu-pnp.csv]
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2018-08-13 0.4.6: tomu: silabs is the manufacturer for the efm32
    [tomu-bom.csv]
2018-08-13 pcb: set manufacturer of the EFM32 to "Silabs"
    [tomu.sch]
2018-09-11 README: correct BOM for capacitor count
    As per issue #32, the list of capacitors was off. This wouldn't have
    resulted in a failed component, but it was really confusing to users who
    were trying to reconcile the BOM with the schematics.
2018-09-11 README: correct (once again) capacitor listing
    There is no 10 nF cap, it's 2x 1nF caps.
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2019-05-30 case: README: fix link to "Manufactured"
    Fix the link to the "manufactured" STEP file.
2021-11-09 Update README.md
    https://forum.kicad.info/t/warning-avoid-all-links-to-kicad-pcb-org-use-kicad-org/31521
